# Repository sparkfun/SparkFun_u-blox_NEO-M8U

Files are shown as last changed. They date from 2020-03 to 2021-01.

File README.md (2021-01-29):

SparkFun GPS Dead Reckoning Breakout - NEO-M8U (Qwiic)
========================================

SparkFun GPS Dead Reckoning Breakout - NEO-M8U (Qwiic) (https://www.sparkfun.com/products/16329)

[SparkFun GPS Dead Reckoning Breakout - NEO-M8U (Qwiic) [GPS-16329]](https://www.sparkfun.com/products/16329)

The SparkFun NEO-M8U GPS Breakout is a high quality, GPS board with equally impressive configuration options. The NEO-M8U takes advantage of u-blox's Untethered Dead Reckoning (UDR) technology. The module provides continuous navigation without needing to make any electrical connection to a vehicle, thus reducing cost of installation for after-market dead reckoning applications. 

The NEO-M8U module is a 72-channel u-blox M8 engine GNSS receiver, meaning it can receive signals from the GPS, GLONASS, Galileo, and BeiDou constellations with ~2.5 meter accuracy. The module supports concurrent reception of three GNSS systems. The combination of GNSS and integrated 3D sensor measurements on the NEO-M8U provide accurate, real-time positioning rates of up to 30Hz. 

Compared to other GPS modules, this breakout maximizes position accuracy in dense cities or covered areas. Even under poor signal conditions, continuous positioning is provided in urban environments and is also available during complete signal loss (e.g. short tunnels and parking garages). With UDR, position begins as soon as power is applied to the board even before the first GNSS fix is available! Lock time is further reduced with on-board rechargeable battery; you'll have backup power enabling the GPS to get a hot lock within seconds!

Additionally, this u-blox receiver supports I<sup>2</sup>C (u-blox calls this Display Data Channel) which made it perfect for the Qwiic compatibility so we don't have to use up our precious UART ports. Utilizing our handy Qwiic system, no soldering is required to connect it to the rest of your system. However, we still have broken out 0.1"-spaced pins in case you prefer to use a breadboard. 

U-blox based GPS products are configurable using the popular, but dense, windows program called u-center. Plenty of different functions can be configured on the NEO-M8U: baud rates, update rates, geofencing, spoofing detection, external interrupts, SBAS/D-GPS, etc. All of this can be done within the SparkFun Arduino Library!

The SparkFun NEO-M8U GPS Breakout is also equipped with an on-board rechargeable battery that provides power to the RTC on the NEO-M8U.  This reduces the time-to-first fix from a cold start (~26s) to a hot start (~1.5s). The battery will maintain RTC and GNSS orbit data without being connected to power for plenty of time.

Repository Contents
-------------------

* **/Documentation** - Data sheets for the NEO-M8U
* **/Hardware** - Eagle design files (.brd, .sch)
* **/Production** - Production panel files (.brd)

Documentation
--------------
* **[Library](https://github.com/sparkfun/SparkFun_u-blox_GNSS_Arduino_Library)** - Arduino Library the SparkFun GPS ublox products.
* **[Hookup Guide](https://learn.sparkfun.com/tutorials/1166)** - Basic hookup guide for the SparkFun GPS NEO-M8U

License Information
-------------------

This product is _**open source**_! 

Please review the LICENSE.md file for license information. 

If you have any questions or concerns on licensing, please contact technical support on our [SparkFun forums](https://forum.sparkfun.com/viewforum.php?f=152).

Distributed as-is; no warranty is given.

- Your friends at SparkFun.

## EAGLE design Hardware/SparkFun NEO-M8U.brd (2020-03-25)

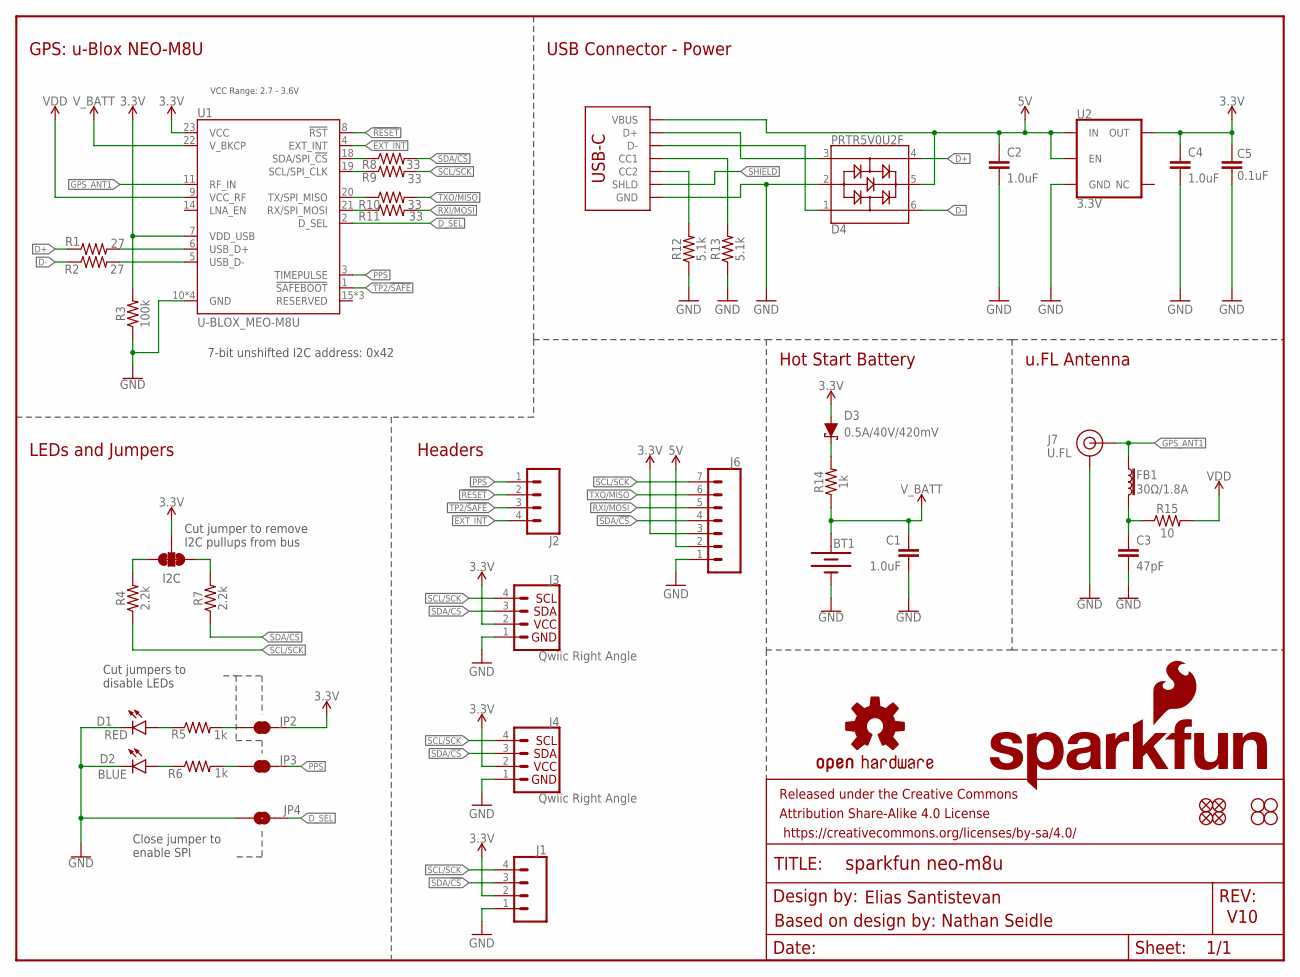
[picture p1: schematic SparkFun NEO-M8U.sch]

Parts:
BT1: 6.8MM_COIN_CELL; ML414H_IV01E
C1, C2, C4: 1.0uF; 0603
C3: 47pF; 0603
C5: 0.1uF; 0603
D1: RED; LED-0603
D2: BLUE; LED-0603
D3: 0.5A/40V/420mV; SOD-323
D4: PRTR5V0U2F; SOT886
FB1: 30Ω/1.8A; 0603
FRAME1: FRAME-LETTER; CREATIVE_COMMONS
J1, J2: CONN_041X04_NO_SILK; 1X04_NO_SILK
J3, J4: Qwiic Right Angle; JST04_1MM_RA
J5: USB_C_2-LAYER_PADS; USB-C-16P-2LAYER-PADS
J6: CONN_07NO_SILK; 1X07_NO_SILK
J7: U.FL
JP1: JUMPER-SMT_3_2-NC_TRACE_SILK; SMT-JUMPER_3_2-NC_TRACE_SILK
JP2, JP3: JUMPER-SMT_2_NC_TRACE_SILK; SMT-JUMPER_2_NC_TRACE_SILK
JP4: JUMPER-SMT_2_NO_SILK; SMT-JUMPER_2_NO_SILK
JP5, JP6, JP7, JP8: FIDUCIALUFIDUCIAL; MICRO-FIDUCIAL
JP9, JP10, JP11, JP12: STAND-OFF
LOGO1: OSHW-LOGOMINI; OSHW-LOGO-MINI
LOGO2: SFE_LOGO_NAME_FLAME.1_INCH; SFE_LOGO_NAME_FLAME_.1
R1, R2: 27; 0603
R3: 100k; 0603
R4, R7: 2.2k; 0603
R5, R6, R14: 1k; 0603
R8, R9, R10, R11: 33; 0603
R12, R13: 5.1k; 0603
R15: 10; 0603
U1: U-BLOX_MEO-M8U; NEO-M9N/M8T/M8U
U2: 3.3V; SOT23-5

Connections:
3.3V: C4.1, C5.2, D3.A, J1.2, J3.2, J4.2, J6.3, JP1.2, JP2.2, R3.2, U1.7 (VDD_USB), U1.23 (VCC), U2.5 (OUT)
5V: C2.1, D4.5, J5.VBUS1 (VBUS), J5.VBUS2 (VBUS), J6.2, U2.1 (IN), U2.3 (EN)
!RESET: J2.2, U1.8 (!RST)
ANT_VCC: C3.1, FB1.2, R15.1
D+: D4.4, R1.1
D-: D4.6, R2.1
D_SEL: JP4.2, U1.2 (D_SEL)
EXT_INT: J2.4, U1.4 (EXT_INT)
GND: BT1.-, C1.2, C2.2, C3.2, C4.2, C5.1, D1.C, D2.C, D4.2, J1.1, J3.1, J4.1, J5.GND, J5.GND2 (GND), J6.1, J7.1 (GND), J7.2 (GND), JP4.1, R3.1, R12.1, R13.1, U1.10 (GND), U1.12 (GND), U1.13 (GND), U1.24 (GND), U2.2 (GND)
GPS_ANT1: FB1.1, J7.FEED (SIGNAL), U1.11 (RF_IN)
unnamed: JP2.1, R5.2
unnamed: D2.A, R6.1
unnamed: R8.1, U1.18 (SDA/SPI_!CS!)
unnamed: JP3.1, R6.2
unnamed: JP1.1, R7.2
unnamed: D3.C, R14.2
unnamed: J5.B5 (CC2), R12.2
unnamed: JP1.3, R4.2
unnamed: J5.A5 (CC1), R13.2
unnamed: D1.A, R5.1
unnamed: R1.2, U1.6 (USB_D+)
unnamed: R2.2, U1.5 (USB_D-)
unnamed: R9.1, U1.19 (SCL/SPI_CLK)
unnamed: R10.1, U1.20 (TX/SPI_MISO)
unnamed: R11.1, U1.21 (RX/SPI_MOSI)
PPS: J2.1, JP3.2, U1.3 (TIMEPULSE)
RXI/MOSI: J6.5, R11.2
SCL/SCK: J1.4, J3.4, J4.4, J6.7, R4.1, R9.2
SDA/!CS: J1.3, J3.3, J4.3, J6.4, R7.1, R8.2
SHIELD: J5.SHLD1 (SHLD), J5.SHLD2 (SHLD), J5.SHLD3 (SHLD), J5.SHLD4 (SHLD)
TP2/!SAFE: J2.3, U1.1 (!SAFEBOOT!)
TXO/MISO: J6.6, R10.2
USB_D+: D4.3, J5.A6 (D+), J5.B6 (D+)
USB_D-: D4.1, J5.A7 (D-), J5.B7 (D-)
VDD: R15.2, U1.9 (VCC_RF)
V_BATT: BT1.+, C1.1, R14.1, U1.22 (V_BKCP)

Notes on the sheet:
V10
7-bit unshifted I2C address: 0x42
Cut jumper to remove I2C pullups from bus
Cut jumpers to disable LEDs
Close jumper to enable SPI
Elias Santistevan
Headers
LEDs and Jumpers
Hot Start Battery
GPS: u-Blox NEO-M8U
u.FL Antenna
USB Connector - Power
Based on design by: Nathan Seidle
VCC Range: 2.7 - 3.6V
I2C

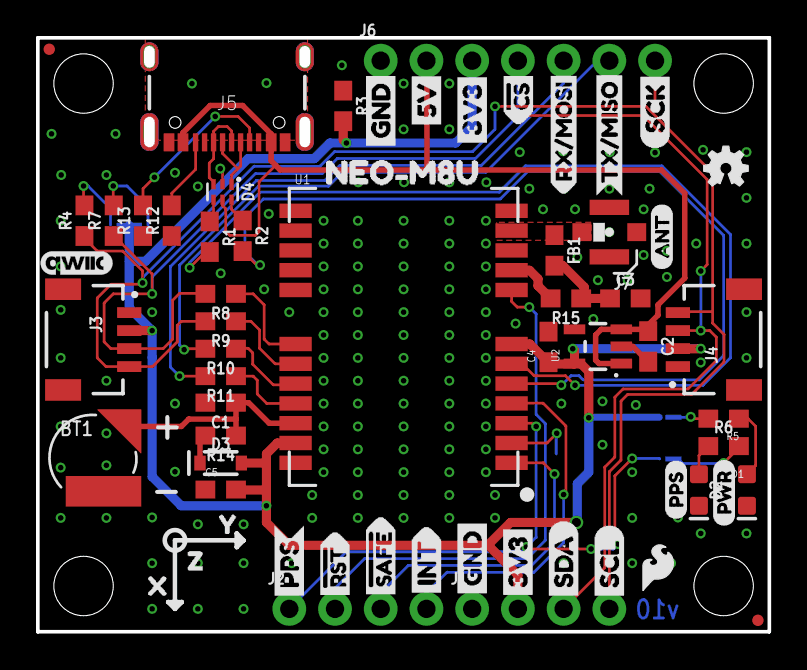
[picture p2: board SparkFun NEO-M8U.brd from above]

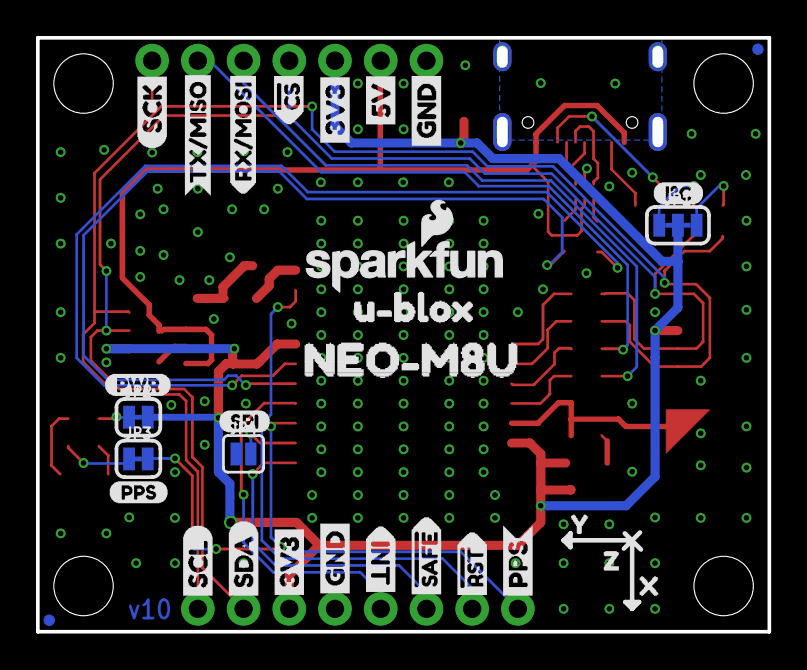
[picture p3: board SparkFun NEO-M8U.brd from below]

Board: 2 copper layers, 40.6 x 33.0 mm, 98 parts (31 on the bottom side), 36 nets.

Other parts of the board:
U$1, U$4: SDA-[)
U$2: INT1
U$3, U$5: SCL-[)
U$6, U$7, U$60, U$61: 3V3-04
U$8, U$9, U$62, U$63: GND-04
U$10: I_SUPER2_C-()-03
U$11: SPI1
U$12, U$52: PPS0
U$13, U$16: X1
U$14: QWIIC_4MM
U$15, U$34: NEO#M8U0
U$17: PWR1
U$18: PWR-()-03
U$19, U$20: 5V
U$21, U$27: Y2
U$22: U#BLOX3
U$23, U$24: CS#-<]
U$25: ANT0
U$26, U$31: RX#MOSI3
U$28, U$30: Z0
U$29, U$37: TX#MISO1
U$32: INT0
U$33: SFE_LOGO_FLAME_.1
U$35, U$36: #RST3
U$38, U$41: SCK-(]-04
U$39, U$40: #SAFE1
U$43, U$44: PPS5

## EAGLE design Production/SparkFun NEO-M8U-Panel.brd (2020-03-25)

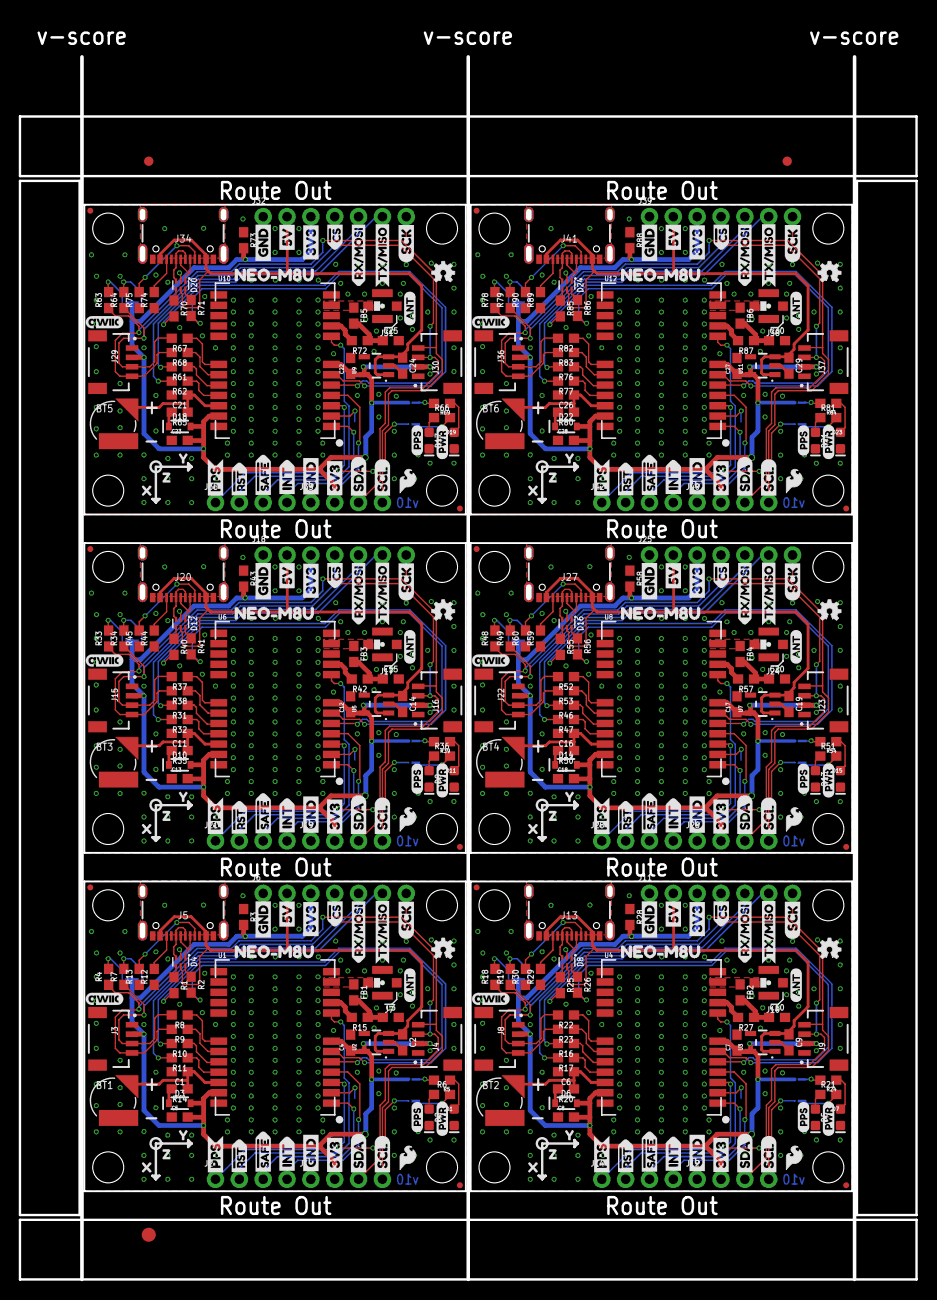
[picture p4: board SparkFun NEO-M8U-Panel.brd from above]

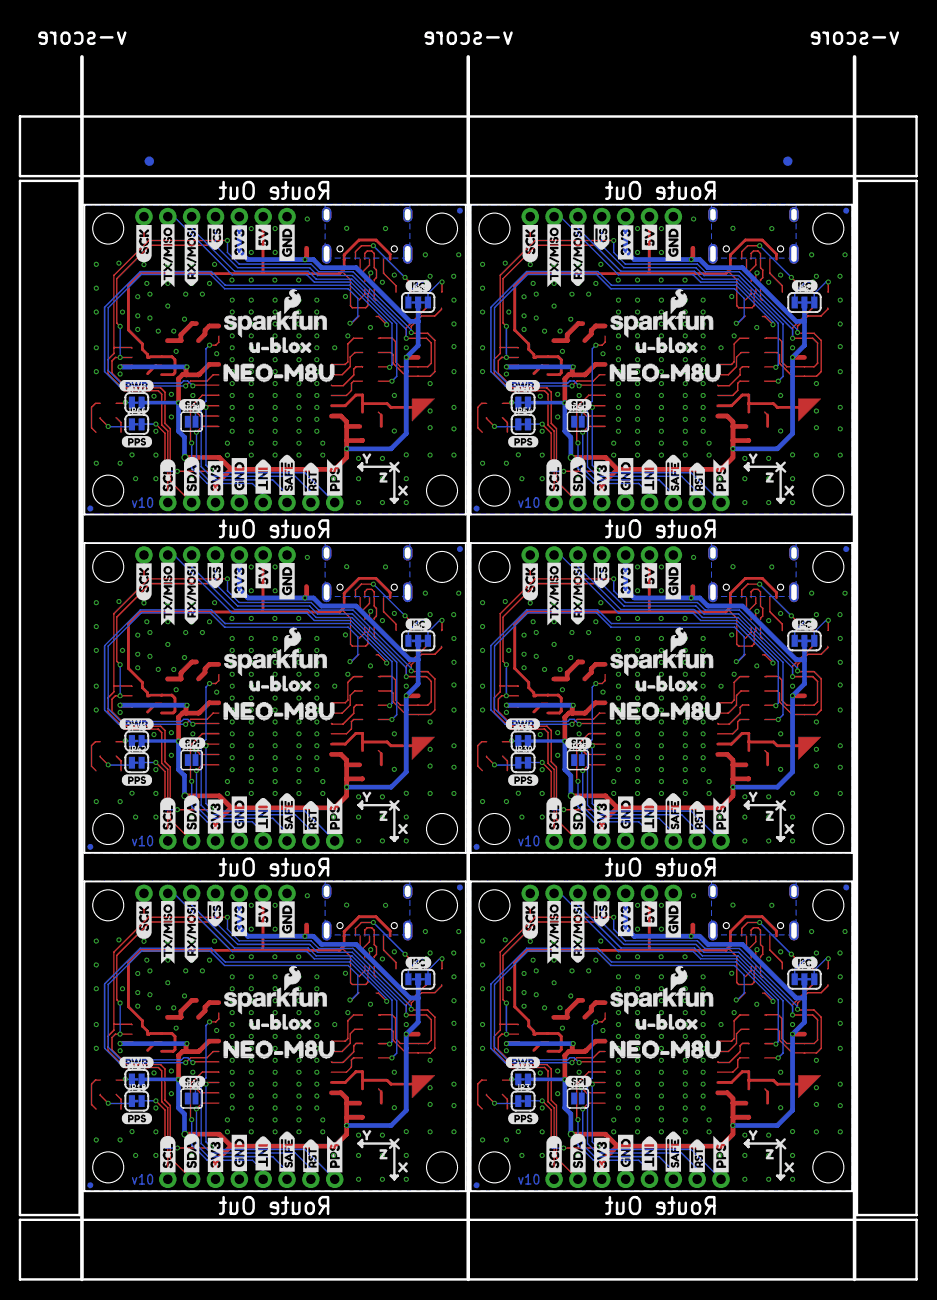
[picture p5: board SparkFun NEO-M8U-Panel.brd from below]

Board: 2 copper layers, 95.5 x 130.2 mm, 587 parts (188 on the bottom side), 216 nets.

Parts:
BT1, BT2, BT3, BT4, BT5, BT6: 6.8MM_COIN_CELL; ML414H_IV01E
C1, C2, C4, C6, C7, C9, C11, C12, C14, C16, C17, C19, C21, C22, C24, C26, C27, C29: 1.0uF; 0603
C3, C10, C15, C20, C25, C30: 47pF; 0603
C5, C8, C13, C18, C23, C28: 0.1uF; 0603
D1, D7, D11, D15, D19, D23: RED; LED-0603
D2, D5, D9, D13, D17, D21: BLUE; LED-0603
D3, D6, D10, D14, D18, D22: 0.5A/40V/420mV; SOD-323
D4, D8, D12, D16, D20, D24: PRTR5V0U2F; SOT886
E$1, E$2, E$3, E$4: FIDUCIAL-1X2
E$5: FIDUCIAL-1.5X3
FB1, FB2, FB3, FB4, FB5, FB6: 30Ω/1.8A; 0603
J1, J2, J12, J14, J19, J21, J26, J28, J33, J35, J40, J42: 1X04_NO_SILK
J3, J4, J8, J9, J15, J16, J22, J23, J29, J30, J36, J37: Qwiic Right Angle; JST04_1MM_RA
J5, J13, J20, J27, J34, J41: USB-C-16P-2LAYER-PADS
J6, J11, J18, J25, J32, J39: 1X07_NO_SILK
J7, J10, J17, J24, J31, J38: U.FL
JP1, JP17, JP29, JP41, JP53, JP65: JUMPER-SMT_3_2-NC_TRACE_SILK; SMT-JUMPER_3_2-NC_TRACE_SILK
JP2, JP3, JP18, JP24, JP30, JP36, JP42, JP48, JP54, JP60, JP66, JP72: JUMPER-SMT_2_NC_TRACE_SILK; SMT-JUMPER_2_NC_TRACE_SILK
JP4, JP23, JP35, JP47, JP59, JP71: JUMPER-SMT_2_NO_SILK; SMT-JUMPER_2_NO_SILK
JP5, JP6, JP7, JP8, JP15, JP16, JP19, JP20, JP27, JP28, JP31, JP32, JP39, JP40, JP43, JP44, JP51, JP52, JP55, JP56, JP63, JP64, JP67, JP68: FIDUCIALUFIDUCIAL; MICRO-FIDUCIAL
JP9, JP10, JP11, JP12, JP13, JP14, JP21, JP22, JP25, JP26, JP33, JP34, JP37, JP38, JP45, JP46, JP49, JP50, JP57, JP58, JP61, JP62, JP69, JP70: STAND-OFF
LOGO1, LOGO3, LOGO5, LOGO7, LOGO9, LOGO11: OSHW-LOGOMINI; OSHW-LOGO-MINI
LOGO2, LOGO4, LOGO6, LOGO8, LOGO10, LOGO12: SFE_LOGO_NAME_FLAME.1_INCH; SFE_LOGO_NAME_FLAME_.1
R1, R2, R25, R26, R40, R41, R55, R56, R70, R71, R85, R86: 27; 0603
R3, R28, R43, R58, R73, R88: 100k; 0603
R4, R7, R18, R19, R33, R34, R48, R49, R63, R64, R78, R79: 2.2k; 0603
R5, R6, R14, R20, R21, R24, R35, R36, R39, R50, R51, R54, R65, R66, R69, R80, R81, R84: 1k; 0603
R8, R9, R10, R11, R16, R17, R22, R23, R31, R32, R37, R38, R46, R47, R52, R53, R61, R62, R67, R68, R76, R77, R82, R83: 33; 0603
R12, R13, R29, R30, R44, R45, R59, R60, R74, R75, R89, R90: 5.1k; 0603
R15, R27, R42, R57, R72, R87: 10; 0603
U1, U4, U6, U8, U10, U12: U-BLOX_MEO-M8U; NEO-M9N/M8T/M8U
U2, U3, U5, U7, U9, U11: 3.3V; SOT23-5
U$1, U$4, U$42, U$46, U$97, U$99, U$145, U$147, U$193, U$195, U$241, U$243: SDA-[)
U$2, U$94, U$142, U$190, U$238, U$286: INT1
U$3, U$5, U$45, U$47, U$98, U$100, U$146, U$148, U$194, U$196, U$242, U$244: SCL-[)
U$6, U$7, U$48, U$49, U$60, U$61, U$66, U$67, U$101, U$102, U$114, U$115, U$149, U$150, U$162, U$163, U$197, U$198, U$210, U$211, U$245, U$246, U$258, U$259: 3V3-04
U$8, U$9, U$50, U$51, U$62, U$63, U$68, U$69, U$103, U$104, U$116, U$117, U$151, U$152, U$164, U$165, U$199, U$200, U$212, U$213, U$247, U$248, U$260, U$261: GND-04
U$10, U$53, U$105, U$153, U$201, U$249: I_SUPER2_C-()-03
U$11, U$80, U$128, U$176, U$224, U$272: SPI1
U$12, U$52, U$65, U$82, U$113, U$130, U$161, U$178, U$209, U$226, U$257, U$274: PPS0
U$13, U$16, U$85, U$91, U$133, U$139, U$181, U$187, U$229, U$235, U$277, U$283: X1
U$14, U$81, U$129, U$177, U$225, U$273: QWIIC_4MM
U$15, U$34, U$90, U$96, U$138, U$144, U$186, U$192, U$234, U$240, U$282, U$288: NEO#M8U0
U$17, U$83, U$131, U$179, U$227, U$275: PWR1
U$18, U$70, U$118, U$166, U$214, U$262: PWR-()-03
U$19, U$20, U$71, U$72, U$119, U$120, U$167, U$168, U$215, U$216, U$263, U$264: 5V
U$21, U$27, U$86, U$92, U$134, U$140, U$182, U$188, U$230, U$236, U$278, U$284: Y2
U$22, U$54, U$106, U$154, U$202, U$250: U#BLOX3
U$23, U$24, U$73, U$74, U$121, U$122, U$169, U$170, U$217, U$218, U$265, U$266: CS#-<]
U$25, U$84, U$132, U$180, U$228, U$276: ANT0
U$26, U$31, U$78, U$88, U$126, U$136, U$174, U$184, U$222, U$232, U$270, U$280: RX#MOSI3
U$28, U$30, U$87, U$93, U$135, U$141, U$183, U$189, U$231, U$237, U$279, U$285: Z0
U$29, U$37, U$79, U$89, U$127, U$137, U$175, U$185, U$223, U$233, U$271, U$281: TX#MISO1
U$32, U$95, U$143, U$191, U$239, U$287: INT0
U$33, U$77, U$125, U$173, U$221, U$269: SFE_LOGO_FLAME_.1
U$35, U$36, U$55, U$56, U$107, U$108, U$155, U$156, U$203, U$204, U$251, U$252: #RST3
U$38, U$41, U$75, U$76, U$123, U$124, U$171, U$172, U$219, U$220, U$267, U$268: SCK-(]-04
U$39, U$40, U$57, U$58, U$109, U$110, U$157, U$158, U$205, U$206, U$253, U$254: #SAFE1
U$43, U$44, U$59, U$64, U$111, U$112, U$159, U$160, U$207, U$208, U$255, U$256: PPS5

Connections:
3.3V: C4.1, C5.2, D3.A, J1.2, J3.2, J4.2, J6.3, JP1.2, JP2.2, R3.2, U1.7, U1.23, U2.5
3.3V1: C7.1, C8.2, D6.A, J8.2, J9.2, J11.3, J12.2, JP17.2, JP24.2, R28.2, U3.5, U4.7, U4.23
3.3V2: C12.1, C13.2, D10.A, J15.2, J16.2, J18.3, J19.2, JP29.2, JP36.2, R43.2, U5.5, U6.7, U6.23
3.3V3: C17.1, C18.2, D14.A, J22.2, J23.2, J25.3, J26.2, JP41.2, JP48.2, R58.2, U7.5, U8.7, U8.23
3.3V4: C22.1, C23.2, D18.A, J29.2, J30.2, J32.3, J33.2, JP53.2, JP60.2, R73.2, U9.5, U10.7, U10.23
3.3V5: C27.1, C28.2, D22.A, J36.2, J37.2, J39.3, J40.2, JP65.2, JP72.2, R88.2, U11.5, U12.7, U12.23
5V: C2.1, D4.5, J5.VBUS1, J5.VBUS2, J6.2, U2.1, U2.3
5V1: C9.1, D8.5, J11.2, J13.VBUS1, J13.VBUS2, U3.1, U3.3
5V2: C14.1, D12.5, J18.2, J20.VBUS1, J20.VBUS2, U5.1, U5.3
5V3: C19.1, D16.5, J25.2, J27.VBUS1, J27.VBUS2, U7.1, U7.3
5V4: C24.1, D20.5, J32.2, J34.VBUS1, J34.VBUS2, U9.1, U9.3
5V5: C29.1, D24.5, J39.2, J41.VBUS1, J41.VBUS2, U11.1, U11.3
!RESET: J2.2, U1.8
!RESET1: J14.2, U4.8
!RESET2: J21.2, U6.8
!RESET3: J28.2, U8.8
!RESET4: J35.2, U10.8
!RESET5: J42.2, U12.8
ANT_VCC: C3.1, FB1.2, R15.1
ANT_VCC1: C10.1, FB2.2, R27.1
ANT_VCC2: C15.1, FB3.2, R42.1
ANT_VCC3: C20.1, FB4.2, R57.1
ANT_VCC4: C25.1, FB5.2, R72.1
ANT_VCC5: C30.1, FB6.2, R87.1
D+: D4.4, R1.1
D+1: D8.4, R25.1
D+2: D12.4, R40.1
D+3: D16.4, R55.1
D+4: D20.4, R70.1
D+5: D24.4, R85.1
D-: D4.6, R2.1
D-1: D8.6, R26.1
D-2: D12.6, R41.1
D-3: D16.6, R56.1
D-4: D20.6, R71.1
D-5: D24.6, R86.1
D_SEL: JP4.2, U1.2
D_SEL1: JP23.2, U4.2
D_SEL2: JP35.2, U6.2
D_SEL3: JP47.2, U8.2
D_SEL4: JP59.2, U10.2
D_SEL5: JP71.2, U12.2
EXT_INT: J2.4, U1.4
EXT_INT1: J14.4, U4.4
EXT_INT2: J21.4, U6.4
EXT_INT3: J28.4, U8.4
EXT_INT4: J35.4, U10.4
EXT_INT5: J42.4, U12.4
GND: BT1.-, C1.2, C2.2, C3.2, C4.2, C5.1, D1.C, D2.C, D4.2, J1.1, J3.1, J4.1, J5.GND, J5.GND2, J6.1, J7.1, J7.2, JP4.1, R3.1, R12.1, R13.1, U1.10, U1.12, U1.13, U1.24, U2.2
GND1: BT2.-, C6.2, C7.2, C8.1, C9.2, C10.2, D5.C, D7.C, D8.2, J8.1, J9.1, J10.1, J10.2, J11.1, J12.1, J13.GND, J13.GND2, JP23.1, R28.1, R29.1, R30.1, U3.2, U4.10, U4.12, U4.13, U4.24
GND2: BT3.-, C11.2, C12.2, C13.1, C14.2, C15.2, D9.C, D11.C, D12.2, J15.1, J16.1, J17.1, J17.2, J18.1, J19.1, J20.GND, J20.GND2, JP35.1, R43.1, R44.1, R45.1, U5.2, U6.10, U6.12, U6.13, U6.24
GND3: BT4.-, C16.2, C17.2, C18.1, C19.2, C20.2, D13.C, D15.C, D16.2, J22.1, J23.1, J24.1, J24.2, J25.1, J26.1, J27.GND, J27.GND2, JP47.1, R58.1, R59.1, R60.1, U7.2, U8.10, U8.12, U8.13, U8.24
GND4: BT5.-, C21.2, C22.2, C23.1, C24.2, C25.2, D17.C, D19.C, D20.2, J29.1, J30.1, J31.1, J31.2, J32.1, J33.1, J34.GND, J34.GND2, JP59.1, R73.1, R74.1, R75.1, U9.2, U10.10, U10.12, U10.13, U10.24
GND5: BT6.-, C26.2, C27.2, C28.1, C29.2, C30.2, D21.C, D23.C, D24.2, J36.1, J37.1, J38.1, J38.2, J39.1, J40.1, J41.GND, J41.GND2, JP71.1, R88.1, R89.1, R90.1, U11.2, U12.10, U12.12, U12.13, U12.24
GPS_ANT1: FB1.1, J7.FEED, U1.11
GPS_ANT2: FB2.1, J10.FEED, U4.11
GPS_ANT3: FB3.1, J17.FEED, U6.11
GPS_ANT4: FB4.1, J24.FEED, U8.11
GPS_ANT5: FB5.1, J31.FEED, U10.11
GPS_ANT6: FB6.1, J38.FEED, U12.11
unnamed: JP2.1, R5.2
unnamed: D2.A, R6.1
unnamed: R8.1, U1.18
unnamed: JP3.1, R6.2
unnamed: JP1.1, R7.2
unnamed: D3.C, R14.2
unnamed: J5.B5, R12.2
unnamed: JP1.3, R4.2
unnamed: J5.A5, R13.2
unnamed: D1.A, R5.1
unnamed: R1.2, U1.6
unnamed: R2.2, U1.5
unnamed: R9.1, U1.19
unnamed: JP17.1, R19.2
unnamed: R10.1, U1.20
unnamed: R11.1, U1.21
unnamed: JP17.3, R18.2
unnamed: D5.A, R21.1
unnamed: JP18.1, R21.2
unnamed: D6.C, R20.2
unnamed: D7.A, R24.1
unnamed: R25.2, U4.6
unnamed: R26.2, U4.5
unnamed: JP24.1, R24.2
unnamed: J13.B5, R29.2
unnamed: J13.A5, R30.2
unnamed: R22.1, U4.18
unnamed: R23.1, U4.19
unnamed: R16.1, U4.20
unnamed: R17.1, U4.21
unnamed: JP29.1, R34.2
unnamed: JP29.3, R33.2
unnamed: D9.A, R36.1
unnamed: JP30.1, R36.2
unnamed: D10.C, R35.2
unnamed: D11.A, R39.1
unnamed: R40.2, U6.6
unnamed: R41.2, U6.5
unnamed: JP36.1, R39.2
unnamed: J20.B5, R44.2
unnamed: J20.A5, R45.2
unnamed: R37.1, U6.18
unnamed: R38.1, U6.19
unnamed: R31.1, U6.20
unnamed: R32.1, U6.21
unnamed: JP41.1, R49.2
unnamed: JP41.3, R48.2
unnamed: D13.A, R51.1
unnamed: JP42.1, R51.2
unnamed: D14.C, R50.2
unnamed: D15.A, R54.1
unnamed: R55.2, U8.6
unnamed: R56.2, U8.5
unnamed: JP48.1, R54.2
unnamed: J27.B5, R59.2
unnamed: J27.A5, R60.2
unnamed: R52.1, U8.18
unnamed: R53.1, U8.19
unnamed: R46.1, U8.20
unnamed: R47.1, U8.21
unnamed: JP53.1, R64.2
unnamed: JP53.3, R63.2
unnamed: D17.A, R66.1
unnamed: JP54.1, R66.2
unnamed: D18.C, R65.2
unnamed: D19.A, R69.1
unnamed: R70.2, U10.6
unnamed: R71.2, U10.5
unnamed: JP60.1, R69.2
unnamed: J34.B5, R74.2
unnamed: J34.A5, R75.2
unnamed: R67.1, U10.18
unnamed: R68.1, U10.19
unnamed: R61.1, U10.20
unnamed: R62.1, U10.21
unnamed: JP65.1, R79.2
unnamed: JP65.3, R78.2
unnamed: D21.A, R81.1
unnamed: JP66.1, R81.2
unnamed: D22.C, R80.2
unnamed: D23.A, R84.1
unnamed: R85.2, U12.6
unnamed: R86.2, U12.5
unnamed: JP72.1, R84.2
unnamed: J41.B5, R89.2
unnamed: J41.A5, R90.2
unnamed: R82.1, U12.18
unnamed: R83.1, U12.19
unnamed: R76.1, U12.20
unnamed: R77.1, U12.21
PPS: J2.1, JP3.2, U1.3
PPS1: J14.1, JP18.2, U4.3
PPS2: J21.1, JP30.2, U6.3
PPS3: J28.1, JP42.2, U8.3
PPS4: J35.1, JP54.2, U10.3
PPS5: J42.1, JP66.2, U12.3
RXI/MOSI: J6.5, R11.2
RXI/MOSI1: J11.5, R17.2
RXI/MOSI2: J18.5, R32.2
RXI/MOSI3: J25.5, R47.2
RXI/MOSI4: J32.5, R62.2
RXI/MOSI5: J39.5, R77.2
SCL/SCK: J1.4, J3.4, J4.4, J6.7, R4.1, R9.2
SCL/SCK1: J8.4, J9.4, J11.7, J12.4, R18.1, R23.2
SCL/SCK2: J15.4, J16.4, J18.7, J19.4, R33.1, R38.2
SCL/SCK3: J22.4, J23.4, J25.7, J26.4, R48.1, R53.2
SCL/SCK4: J29.4, J30.4, J32.7, J33.4, R63.1, R68.2
SCL/SCK5: J36.4, J37.4, J39.7, J40.4, R78.1, R83.2
SDA/!CS: J1.3, J3.3, J4.3, J6.4, R7.1, R8.2
SDA/!CS1: J8.3, J9.3, J11.4, J12.3, R19.1, R22.2
SDA/!CS2: J15.3, J16.3, J18.4, J19.3, R34.1, R37.2
SDA/!CS3: J22.3, J23.3, J25.4, J26.3, R49.1, R52.2
SDA/!CS4: J29.3, J30.3, J32.4, J33.3, R64.1, R67.2
SDA/!CS5: J36.3, J37.3, J39.4, J40.3, R79.1, R82.2
SHIELD: J5.SHLD1, J5.SHLD2, J5.SHLD3, J5.SHLD4
SHIELD1: J13.SHLD1, J13.SHLD2, J13.SHLD3, J13.SHLD4
SHIELD2: J20.SHLD1, J20.SHLD2, J20.SHLD3, J20.SHLD4
SHIELD3: J27.SHLD1, J27.SHLD2, J27.SHLD3, J27.SHLD4
SHIELD4: J34.SHLD1, J34.SHLD2, J34.SHLD3, J34.SHLD4
SHIELD5: J41.SHLD1, J41.SHLD2, J41.SHLD3, J41.SHLD4
TP2/!SAFE: J2.3, U1.1
TP2/!SAFE1: J14.3, U4.1
TP2/!SAFE2: J21.3, U6.1
TP2/!SAFE3: J28.3, U8.1
TP2/!SAFE4: J35.3, U10.1
TP2/!SAFE5: J42.3, U12.1
TXO/MISO: J6.6, R10.2
TXO/MISO1: J11.6, R16.2
TXO/MISO2: J18.6, R31.2
TXO/MISO3: J25.6, R46.2
TXO/MISO4: J32.6, R61.2
TXO/MISO5: J39.6, R76.2
USB_D+: D4.3, J5.A6, J5.B6
USB_D+1: D8.3, J13.A6, J13.B6
USB_D+2: D12.3, J20.A6, J20.B6
USB_D+3: D16.3, J27.A6, J27.B6
USB_D+4: D20.3, J34.A6, J34.B6
USB_D+5: D24.3, J41.A6, J41.B6
USB_D-: D4.1, J5.A7, J5.B7
USB_D-1: D8.1, J13.A7, J13.B7
USB_D-2: D12.1, J20.A7, J20.B7
USB_D-3: D16.1, J27.A7, J27.B7
USB_D-4: D20.1, J34.A7, J34.B7
USB_D-5: D24.1, J41.A7, J41.B7
VDD: R15.2, U1.9
VDD1: R27.2, U4.9
VDD2: R42.2, U6.9
VDD3: R57.2, U8.9
VDD4: R72.2, U10.9
VDD5: R87.2, U12.9
V_BATT: BT1.+, C1.1, R14.1, U1.22
V_BATT1: BT2.+, C6.1, R20.1, U4.22
V_BATT2: BT3.+, C11.1, R35.1, U6.22
V_BATT3: BT4.+, C16.1, R50.1, U8.22
V_BATT4: BT5.+, C21.1, R65.1, U10.22
V_BATT5: BT6.+, C26.1, R80.1, U12.22

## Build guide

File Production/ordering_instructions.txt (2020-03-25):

panel size, 96x115mm
PCB thickness, 1.6mm
number of layers, 2
soldermask color, Red
silkscreen color, White
oz copper, 1oz
finish, HASL lead free
stencils, top
pcs per panel, 6
min trace width, 0.1524mm / 0.0060in
min drill size, 0.3048mm / 0.0120in

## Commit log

2020-01-28 Adds supporting files and hardware template
    [SparkFun NEO-M8T.brd, SparkFun NEO-M8T.sch]
2020-01-29 Some updates to the design (heh)
    [SparkFun NEO-M8T.brd, SparkFun NEO-M8T.sch]
2020-01-30 Removes 10k from board
    [SparkFun NEO-M8T.brd, SparkFun NEO-M8T.sch]
2020-01-31 This is now the M8U repo not the M8T
    [SparkFun NEO-M8U.brd, SparkFun NEO-M8U.sch]
2020-02-03 Updates design with the M8U module
    [SparkFun NEO-M8U.brd, SparkFun NEO-M8U.sch]
2020-02-03 Updates the ground and shield pour
    [SparkFun NEO-M8U.brd, SparkFun NEO-M8U.sch]
2020-02-04 Updates design to improve ground pout
    [SparkFun NEO-M8U.brd, SparkFun NEO-M8U.sch]
2020-02-04 Adds silk for the orientation of the IMU
    [SparkFun NEO-M8U.brd]
2020-02-04 Moves a single (yeah) via
    [SparkFun NEO-M8U.brd]
2020-02-05 Moves some silk around - resizes some .015 drill hits to .012
    [SparkFun NEO-M8U.brd]
2020-02-05 Moves battery circuit around for better aesthetic (heh), adjusts various labels
    [SparkFun NEO-M8U.brd]
2020-02-05 Updates old schematic artifacts, replace power lables with their proper symbols
    [SparkFun NEO-M8U.brd, SparkFun NEO-M8U.sch]
2020-02-10 Adds silk - fixes some DRC errors
    [SparkFun NEO-M8U.brd]
2020-02-10 Adds interrupt silk
    [SparkFun NEO-M8U.brd]
2020-02-10 Adds gerbers for prototype
    [SparkFun NEO-M8U.GBL, SparkFun NEO-M8U.GBO, SparkFun NEO-M8U.GBS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]
2020-03-23 Rolls version to v10 and updates all of the parts' packages
    [SparkFun NEO-M8U.brd, SparkFun NEO-M8U.sch]
2020-03-24 Removes old gerbers and buzzard labels, fixes some minor board inconsistencies
    [SparkFun NEO-M8U.GBL, SparkFun NEO-M8U.GBO, SparkFun NEO-M8U.GBS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]
2020-03-24 Updates some silk, removes wire stubs
    [SparkFun NEO-M8U.brd]
2020-03-25 Adjusts some wonky trace widths, moves some traces for better pour
    [SparkFun NEO-M8U.brd, SparkFun NEO-M8U.sch]
2020-03-25 Fixes more trace widths
    [SparkFun NEO-M8U.brd]
2020-03-25 Adds panel for production
    [SparkFun NEO-M8U-Panel.GBL, SparkFun NEO-M8U-Panel.GBO, SparkFun NEO-M8U-Panel.GBP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]
2022-04-07 Fixes "u-blox" typo in schematic
    [SparkFun NEO-M8U.sch]

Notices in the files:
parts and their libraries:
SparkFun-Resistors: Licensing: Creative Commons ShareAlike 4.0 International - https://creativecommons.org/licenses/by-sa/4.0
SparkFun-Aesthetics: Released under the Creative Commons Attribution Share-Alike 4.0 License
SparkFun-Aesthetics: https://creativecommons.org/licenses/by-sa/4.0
